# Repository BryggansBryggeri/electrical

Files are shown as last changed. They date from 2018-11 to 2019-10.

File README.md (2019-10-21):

# electrical
Electronics, hardware schematics

## Ethernet Cable Wiring Guide
| Colour 	| Connector 	| Temp [DS18B20] 	| VFD  	| Pressure 	| Float switch 	| Albus 	|
|---	|---	|---	|---	|---	|---	|---	|
| Orange 	| 1 	| + 	| N/A  	| N/A 	| + 	| N/A 	|
| Blå 	| 2 	| - 	| N/A  	| N/A 	| - 	| N/A 	|
| Brun 	| 3 	| Data 	| N/A  	| N/A 	| N/A 	| N/A 	|
| Grön 	| 4 	| N/A 	| Dif+ 	| N/A 	| N/A 	| N/A 	|
| Grön/Vit 	| 5 	| N/A 	| Dif- 	| N/A 	| N/A 	| N/A 	|

## Panel mounted Contact Orientation

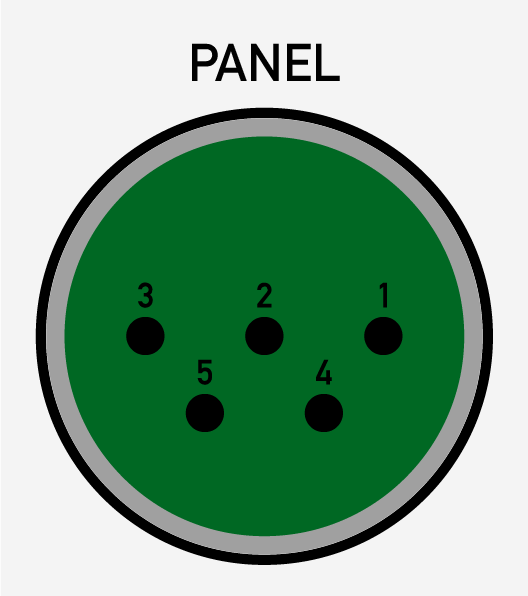
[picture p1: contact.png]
Panel mount diagram


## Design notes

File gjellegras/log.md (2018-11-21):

## 180807

 - Testat ventil med transistorbrygga (ULN2003A). 12V bruten med transistor. Öppnar ventilen med 3.3V styrsignal från Arduino. Ej testat med mjukvarustyrning, men har all anledning och tro att det går.
 - Gjort enkelt kopplingsschema i kicad
 - Tanke: arduino nano, alt. be Erki Pojka om hjälp att göra eget chip.
Idén är att använda färdiga FC-28 fuktsensorer och baserade på analog read släppa på vatten. Idealt också att driva allt med solceller så det är helt självgående. Ingen extern kommunikation i version 1

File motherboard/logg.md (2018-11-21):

# DEVLOGG

## Resources

https://www.makeuseof.com/tag/raspberry-pi-gpio-pins-guide/
https://www.instructables.com/id/Design-a-Raspberry-Pi-Hat-KiCad/

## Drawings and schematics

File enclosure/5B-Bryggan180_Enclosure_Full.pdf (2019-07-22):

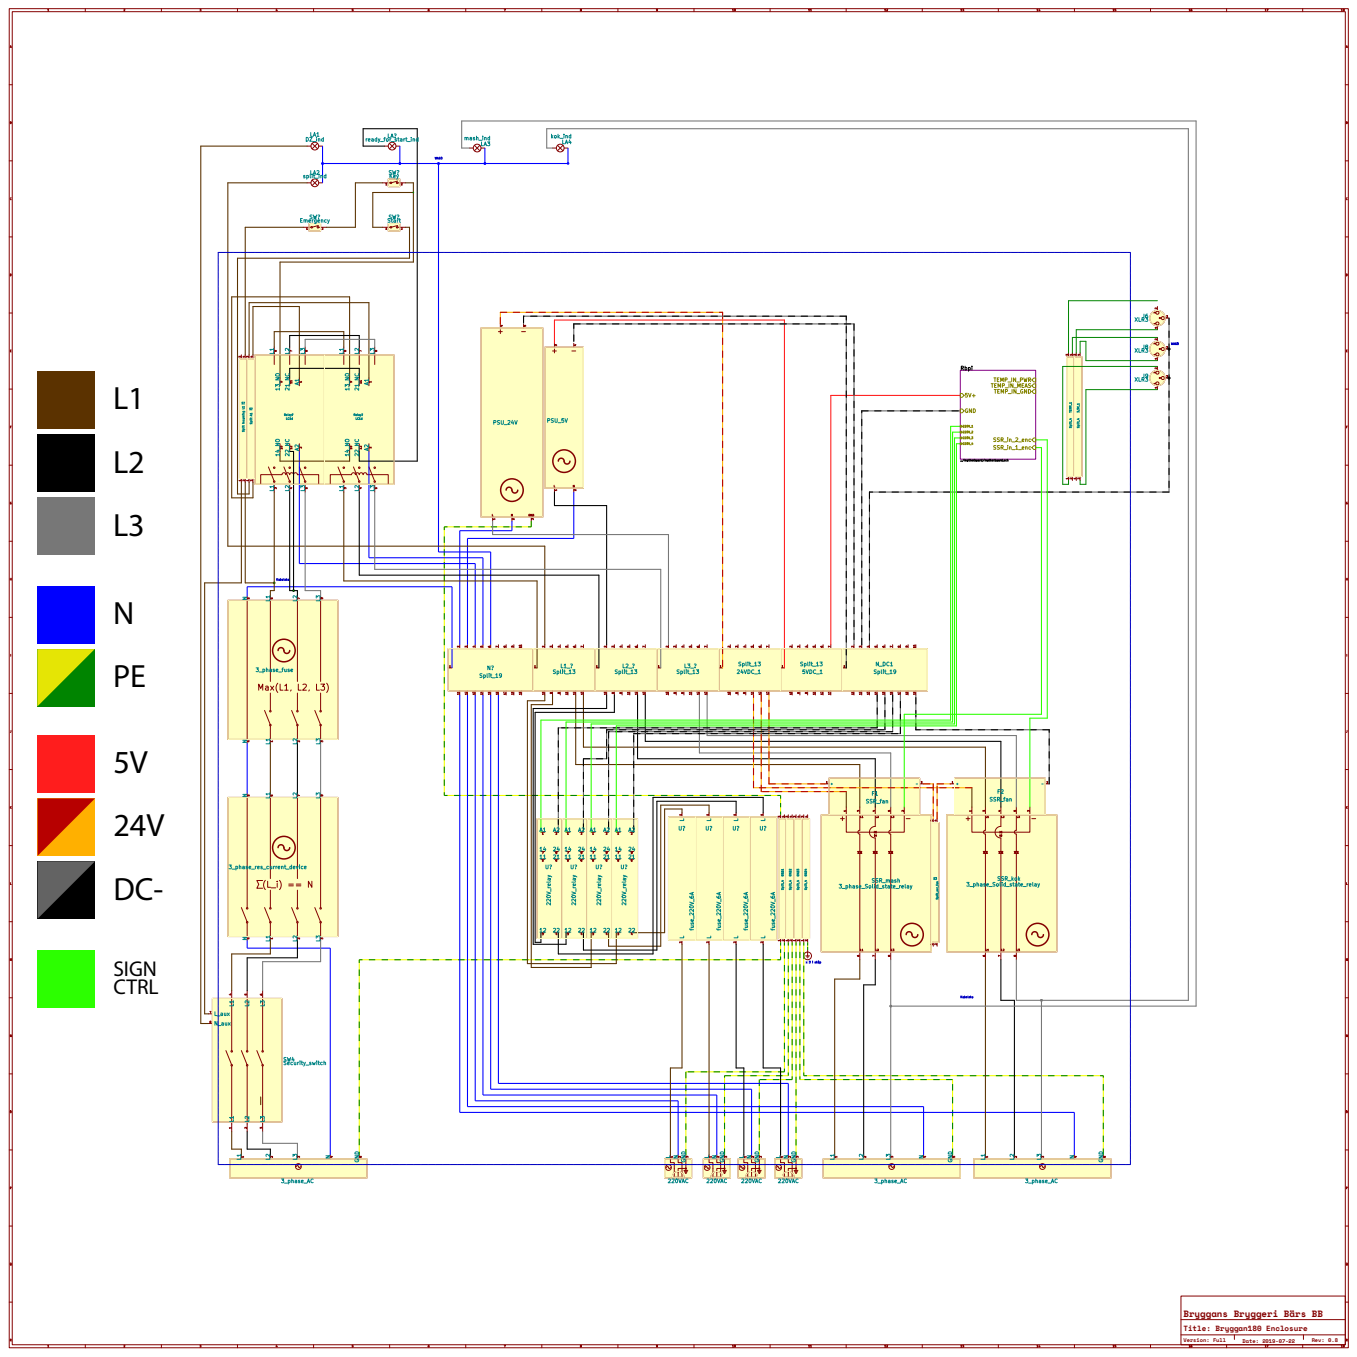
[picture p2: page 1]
Version: Full; Date: 2019-07-22; Rev: 0.8; SIGN CTRL

Bryggans Bryggeri Bärs BB
Title: Bryggan180 Enclosure

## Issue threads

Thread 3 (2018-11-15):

touch screen

jaklindq, 2018-11-15:

JonathanFager, 2019-07-05:
Best would be a used tablet with a rugged case and then a mount on the side of the electrical cabinet (or some other point )

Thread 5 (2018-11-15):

Pump cabinet design

jackonelli, 2018-11-15:
- [x] Decide on dimensions of cabinet
- [x] Decide on cable
- [x] Decide on way to communicate with VFD
- [x] Decide on connectors
- [x] Build

JonathanFager, 2019-05-07:
- [ ] Decide on dimensions of cabinet
- [ ] Decide on cable
- [ ] Decide on way to communicate with VFD
- [ ] Decide on connectors
- [ ] Build

jackonelli, 2019-08-23:
I think we'll branch off a separate issue for the motherboard/rpbi parts of the comm's.
Then we can close this issue if we only decide on cable for comm's between enclosure and pump cabinet.
@swebro any thoughts? RJ45 is expensive so we can use on of those nice ones Jonte found?

Closed 2020-03-20.

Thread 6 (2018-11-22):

opamp comparator for ssr signal indication

jaklindq, 2018-11-22:
Sen så kollar man bara med en opamp i komperator-koppling mellan spänningen vid motståndet och en spänningsreferens (en potentiometer, alla opampar kan använda samma potentiometer som referens), opampen driver i sin tur en led via ett annat motstånd.

Fördelarna med det är att leden bara lyser om det går ström genom SSRen, samt att man isolerar XORen ifrån externa spänningar.

Om man behöver en pull up eller pull down sätter man den parallell med dioden till dit man vill pulla

Closed 2018-12-13.

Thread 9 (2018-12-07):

Double check rbpi pins schema vs footprint

jaklindq, 2018-12-07:

jaklindq, 2018-12-15:
Was correct, although the fact that we mount the rbpi upside down the footprint needed to be rotated to match the mounted pins.

Closed 2018-12-15.

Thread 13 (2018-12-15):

Mosfet swap

jaklindq, 2018-12-15:
Swap places Q1 <--> Q2

Closed 2018-12-16.

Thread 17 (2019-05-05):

Align connectors

jackonelli, 2019-05-05:
Align connectors 2-pin J2-J7 such a 1x8 connector can be used.

They can technically be made into a mutli-unit component since they do not appear in hierarchical sheets used many times.
Not ideal from a schematics point of view but a lot less error prone in the pcb so this is probably best

jackonelli, 2019-08-16:
These connectors does NOT need to be grounded. The transistors just receives the 24VDC signal post load (relay or whatever) and opens to the ground plane on the card. I.e. a single connecting signal path per transistor

jackonelli, 2019-08-16:
Schematically this is actually fine. I moved all connectors to the root of the hierarchical sheets.

jackonelli, 2019-08-16:
Forss approves the removal of ground

Closed 2019-08-19.

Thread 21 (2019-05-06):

Correct power splits

jackonelli, 2019-05-06:
Now that we actually have the ones we are going to use:

 - [x] Make eeschema component
 - [x] Decide placement
 - [x] Switch and rewire

JonathanFager, 2019-05-15:
For the small splits, use 1-to-as many as needed, and we get the jumpers. This will help clean up the schema significantly

Closed 2019-07-01.

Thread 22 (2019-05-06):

VFD in the design

jackonelli, 2019-05-06:
Should we have it in the enclosure? If yes:

- [ ] Eeschema component
- [ ] Decide on placement
- [ ] Wire

JonathanFager, 2019-05-07:
Should not be in the enclosure for now. Closing this issue in favor of #5

Closed 2019-05-07.

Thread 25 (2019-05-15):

220 Outlets Relays

JonathanFager, 2019-05-15:
- [x] eeschema component
- [x] decide on placement
- [x] wire

jackonelli, 2019-07-02:
Be Loka kolla över det nästa gång vi är i lokalen

Closed 2019-08-29.

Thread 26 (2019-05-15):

Fix Start Wiring

JonathanFager, 2019-05-15:
Fix the incorrect implementation of switches for start procedure

Closed 2019-07-01.

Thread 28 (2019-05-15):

Fix Contactor Aux-Relays

JonathanFager, 2019-05-15:
The Contactors have AUX-relays, NO and NC (I think), which could be used for Lights.

Closed 2019-07-01.

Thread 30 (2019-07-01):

Control 220V relays and SSR's with the same driver circuit

jackonelli, 2019-07-01:
I added the hierarchical pins to complete the enclosure kicad but no actual functionality is in the pcb yet

jackonelli, 2019-08-16:
These need the exact same circuit as the SSR driver.
Transition to IC? E.g. http://www.ti.com/lit/ds/symlink/uln2003a.pdf

jackonelli, 2019-08-16:
- Den du länkade är Darlington arrayer, vilket inte är mosfets. Vilket kan vara fine om Raspberryn orkar driva dem

- Ålrajt. Men det finns säkert liknande med många mosfets?

- Det ska det göra
Den där det upp till 1.25mA per ingång, vilket är ganska mycket för Raspberryn
Man får inte dra mer än 16mA per pinne men totalen får inte överstiga 51mA. Det är lätt att glömma det om man börjar koppla på mer och mer saker

- Vi kanske ska gå direkt på en shift register och bara använda 3-pinnar?!?

- Gillar inte shift register. Har man problem med brus kan de vara opålitliga, men i2c io-expanders är nice https://se.farnell.com/microchip/mcp23017t-e-ss/i-o-expansion-16bitar-1-7mhz-ssop/dp/2851558 25mA per pin, 125mA totalt 16 styrbara pinnar i två 8-bitars register. Frågan är om 25mA räcker. Ville inte SSRerna ha typ 45mA, o skulle gissa på att relän vill ha något liknande

swebro, 2019-08-16:
[This](https://se.farnell.com/maxim-integrated-products/max4896etp/rel-drivkrets-8-kan-5-5v-tqfn/dp/2516973) seems like a nice little IC

jackonelli, 2019-08-16:
> [This](https://se.farnell.com/maxim-integrated-products/max4896etp/rel-drivkrets-8-kan-5-5v-tqfn/dp/2516973) seems like a nice little IC
>
> EDIT: It even have Open-Load Detection, so we do not need to implement it ourself.

jackonelli, 2019-08-16:
Closed by mistake.

jackonelli, 2019-08-16:
> [This](https://se.farnell.com/maxim-integrated-products/max4896etp/rel-drivkrets-8-kan-5-5v-tqfn/dp/2516973) seems like a nice little IC
>
> EDIT: It even have Open-Load Detection, so we do not need to implement it ourself.

But can it handle 24V needed for the SSR/relay. It says max Vcc 5.5V but it also says "designed for medium voltage applications up to 50V"

swebro, 2019-08-16:
Yes, it works very similarly to our current design if you look at page 11 of the datasheet.

swebro, 2019-08-16:
If I were to guess, the reason they chose 50V as max is that the internal source-drain capacitance is so large that the energy in the current rush when opening the transistor is enough to arc the junction

swebro, 2019-08-16:
The IC itself is just 5x5mm, so they do not have a lot of room for a wide transistor

jackonelli, 2019-08-16:
We are seriously considering i2c comm for an io expander:
https://www.farnell.com/datasheets/2243622.pdf

jackonelli, 2019-08-19:
Upgrade to opamp with more parallell inputs?

Here is a quad input variant (the tlc272 we currently use is only dual):
https://se.farnell.com/texas-instruments/lm324adr/op-amp-quad-low-power-smd-soic14/dp/8389233

jackonelli, 2019-08-19:
Inspiration:
https://www.abelectronics.co.uk/p/54/io-pi-plus

Closed 2019-08-30.

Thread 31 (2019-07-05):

L1, L2, L3 phases colour error in schematic

jackonelli, 2019-07-05:

jackonelli, 2019-07-05:
När du ändå är igång:
Gör texten nere i höger hörn större också. Skulle bli en mycket finare utskrift

JonathanFager, 2019-07-05:
L1: Brun
L2: Svart
L3: Grå

Closed 2019-08-16.

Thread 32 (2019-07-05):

Floating switch

jackonelli, 2019-07-05:
- [ ] Add to enclosure design
- [ ] Decide on connector
- [ ] Mount connector in enclosure

jackonelli, 2019-07-05:
Indicator is going to be tricky with serial wiring as we have planned.

jackonelli, 2019-08-19:
Simplest option is to have an implicit indicator:

Raspberry GPIO is firing without "AND error" but indicator for SSR is not HIGH. Then it should be the floating switch.

jackonelli, 2019-08-19:
If we want an actual indicator, which would be real nice. Then we could have the floating switch only wired to a Mosfet-style subcircuit which, when floating switch closed, allows SSR signal and indicator to close

JonathanFager, 2019-08-19:
Do we really need an indicator light for this? I agree it should not allow SSR to fire, but a light only for this seems like a feature creep

jackonelli, 2019-08-21:
Feature creep <3. Imagine having a red light go on as we are emptying the mash tun. Undaunted glory.

JonathanFager, 2019-08-30:
We could mount this in a stainless tube that is inserted into the kettles from the top. No need to drill holes.

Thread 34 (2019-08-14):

Serial interface

jackonelli, 2019-08-14:
Will prevent major headaches to have this easily accessible even with active enclosure.

- [ ] Motherboard interface
- [ ] Interior wiring to sensor wall
- [ ] Panel mounted contact (USB)

Cable: https://se.farnell.com/adafruit-industries/954/usb-to-ttl-serial-cable-raspberry/dp/2215041

swebro, 2019-08-14:
I think that having a connector on the PCB so we can have a RJ-RJ cable between it and the connector on the case. [Here](https://github.com/stephane/libmodbus/wiki/Libmodbus-on-Raspberry-pi) is a library to use the internal UART to communicate over modbus, we just need a [tranciever](https://se.farnell.com/analog-devices/adm483earz/transceiver-rs485-250kbps-nsoic/dp/2377088?st=rs485) and a [rs485 line driver](https://www.google.com/search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:) if we want the RPi ti be the master

jackonelli, 2019-08-16:
Sadly, we need the uart pins for the VFD comms.

jackonelli, 2019-08-29:
Terse, and for the rbpi-zero. But this might actually have something:
https://openpunk.com/post/5

Closed 2019-08-16.

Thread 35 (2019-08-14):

Connect all rbpi ground pins to ground plane?

jackonelli, 2019-08-14:

swebro, 2019-08-14:
It depends on a lot of factors. On one hand the stronger ground is connected to itsself the better. But one need to prevent ground loops. [Read this](https://www.autodesk.com/products/eagle/blog/8-pcb-grounding-rules/)

jackonelli, 2019-08-16:
Since the pi itself connects all ground pins to the ground plane, we'll do the same.

Closed 2019-08-16.

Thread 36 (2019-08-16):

Indicator and error signals

jackonelli, 2019-08-16:
These should be feedbacked to rbpi for sure. Do we want lamps on enclosure as well?
The indicators is already in place since we do that directly with one of the SSR output phase (better since we then also show that the SSR is actually working and not only the signal).

The error signal remains. We will still show it (and prohibit it) in software so it is really unlikely that it will ever show.

jackonelli, 2019-08-16:
We'll feedback all the ssr outputs via the i2c io expander #30
error signal will get its own gpio

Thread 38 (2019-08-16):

Calculate total power

jackonelli, 2019-08-16:

JonathanFager, 2019-08-16:
Lamps are 5W each

JonathanFager, 2019-08-16:
Worst case: Fuses trip. Nothing breaks right?

JonathanFager, 2019-08-17:
Fan is 0.062kW

swebro, 2019-10-21:
If we were to draw to much, what could we do about it? Not too much other than limiting the SSR duty cycles. So I think that it is better to measure the currents, for now we could try to borrow a power meter and if we are close we could add one in the system

JonathanFager, 2019-10-22:
Exactly. Our actors could have a property that is powerDraw and Bryggio could make sure that powerDraw never exceeds what we can supply.

For sure Plejd have nice power meeters just laying around.

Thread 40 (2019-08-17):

Add Pressure/Volume sensor

JonathanFager, 2019-08-17:

jackonelli, 2019-08-17:
Not prioritised for first milestones. But nice to drill enclosure parts before mounting in brewery

JonathanFager, 2019-08-19:
There are 2 versions of this. One that delivers an analog signal of 0-5V or one that delivers a signal in the form of mA. Which is to be desired?
@swebro

Also, what is the maximum pressure in kPA that can be expected? Needed to size the sensors correctly. @jackonelli

jackonelli, 2019-08-21:
With 2m fluid height: 121.429 kPa. So that is the absolute maximum.
I'm not sure about the exact height of the vessels

JonathanFager, 2019-08-21:
Boil 52+11.5cm (main+hoptrap)
Assume roughly same on mash

JonathanFager, 2019-08-21:
Boil main volume 158l.
Hoptrap 18l

JonathanFager, 2019-08-21:
70 cm depth gives roughly 7kPa?

jackonelli, 2019-08-21:
I assume we wont be operating the brewery in vacuum?

JonathanFager, 2019-08-21:
It will be very energy efficient to achieve boil of of DMS in a near vacuum.

B stands for Brownian motion

JonathanFager, 2019-08-21:
Now my calculations are not known to be correct. However: I assume that the sensors are calibrated to atmosoherical pressure. So they should be sized go only the added pressure of the water/wort hence 7kPa?

jackonelli, 2019-08-21:
Mais oui

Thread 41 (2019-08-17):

Add Flowsensor

JonathanFager, 2019-08-17:

jackonelli, 2019-08-17:
Not prioritised for first milestones. But nice to drill enclosure parts before mounting in brewery

jackonelli, 2020-03-25:
Verify protocol, see if it works with 0-10V or 4-20mA

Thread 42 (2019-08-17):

Add Enclosure temperature sensor

JonathanFager, 2019-08-17:
A temperature sensor within the enclosure might be a good idea, if only as a temporary thing to monitor cabinet temeperatures and might even in thhe future sound buzzer or trigger E-stop if temperature exceeds say 70oC

jackonelli, 2019-08-17:
Great idea. I think part of it should be implemented. Triggering E-stop seems infeasible though.
How would we control the power to the contactor coil?

jackonelli, 2019-08-17:
We could of course block all output. But not the input?

JonathanFager, 2019-08-19:
I know for a fact that we have a DH11 Sensor lying around. Would be mounted directly on the PCB.
Ping @jackonelli to possibly implement this directly.

JonathanFager, 2019-12-09:
We now got a Ds18b20 in the enclosure.
This works well for all intent and purposes.
Will make a din-clip for ds18b20

JonathanFager, 2019-12-09:
First design iteration, hopefully it'll fit.
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

JonathanFager, 2019-12-09:
[ds18b20clip.zip](https://github.com/BryggansBryggeri/electrical/files/3940114/ds18b20clip.zip)

@jackonelli if you can, please start .gcode file extension on the printer.

JonathanFager, 2019-12-10:
Clip is printed. Probably in the box by the printer at ETA.

Closed 2020-01-25.

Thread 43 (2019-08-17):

Add Buzzer

JonathanFager, 2019-08-17:
Buzzer has two states continuous and pulsing.
Find buzzer and implement this so that both these states can be implemented. i.e Pulse for "Add hops" and Continuous for temperature is to high

jackonelli, 2019-08-17:
Buzzer is in box at ETA

jackonelli, 2019-09-06:
Ø: 26mm. Needs to be mounted on the outside of the enclosure.
Also: needs two separate signal lines: It has three pins, one neutral and two positive.
Positive 1: repeating beep
Positive 2: continuous beep.

Can this be driven low-side? I.e. is it symmetric?

jackonelli, 2019-09-06:
Or we can drive this with continuous signal only, and make beep patterns in software

JonathanFager, 2019-12-10:
Mounting-dinclip is printed. Probably in small box beside printer.
Buzzer is on top of cabinet.

For now, not ideal to have inside of the cabinet, but will have to do for now.

What should the functionality be?

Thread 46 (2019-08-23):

Add temp sensors

jackonelli, 2019-08-23:
- [x] Confirm motherboard v1.0 one-wire interface
- [x] EEschema
- [x] Decide on connectors
- [x] Drill holes for connectors
- [x] Test with connectors

jackonelli, 2019-08-23:
Do we need to "ground" the signal from connector, directly on motherboard for good signal properties?
The alternative is to wire it directly to NDC DIN-split.

==> One less screw terminal on motherboard.

swebro, 2019-08-26:
I would say that it is better to take it to the PCB, otherwise it would be a large zero-resistance loop and would form a quite good transformer

JonathanFager, 2019-10-10:
2 more distances to be made.

Closed 2020-02-09.

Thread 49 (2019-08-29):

Check resistor values

jackonelli, 2019-08-29:
Standardise to this:

https://www.electronics-notes.com/articles/electronic_components/resistors/standard-resistor-values-e-series-e3-e6-e12-e24-e48-e96.php

Also: try to minimise the number of unique R values

swebro, 2020-03-23:
Reminder: Some resistors need to be as close to a specific value as possible

jackonelli, 2020-03-25:
Some calcs left. Will open sub issues. Also did capacitors

Closed 2020-03-25.

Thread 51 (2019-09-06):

PE on SSR

jackonelli, 2019-09-06:
I think they are grounded in the DIN-rail, but there seems to be a dedicated screw for it, see page 6:

http://www.productselection.net/pdf/UK/RGC_2_3A.pdf

swebro, 2019-09-06:
You are correct, it is however normal to have a redundant connection in these kind of components. We could be content with how it is now, but it is better to also connect the ground screw

JonathanFager, 2019-10-10:
Today I crimped two wires for ground. However, they where a PITA to get to.
Measured the resistance from the SSR to different points on the enclosure and it was at max 0.7ohm. => More than good enough
@swebro Please move this back to To Do if you disagree, otherwise close the issue

swebro, 2019-10-17:
It should be good enough

Closed 2019-10-17.

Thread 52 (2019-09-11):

Add extra i2c expander

jackonelli, 2019-09-11:
With two lines required for buzzer(?) #43 we are now filled up

swebro, 2020-03-23:
I've made it easier to add more IO expanders, what do we want them for? Should they all be the same open drain with feedback as the others?

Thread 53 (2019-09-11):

rbpi din mount

jackonelli, 2019-09-11:
- [x] design
- [x] 3d print
- [ ] protective plate / cooling system holder

jackonelli, 2019-09-11:
design at google drive/bryggan180/electrical/raspberry_mount

jackonelli, 2019-09-11:
The print is fine. Need som distances/bottom plate though since the base of the mount interferes with electronic components on pi

JonathanFager, 2019-10-14:
Closing this for now.
If internal temperature is to high during operations, we will open a new issue for this.

Closed 2019-10-14.

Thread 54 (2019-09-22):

Power cord on Boil

JonathanFager, 2019-09-22:
Fix powercord on Boilkettle.
Not much left but some cableshoes.

Closed 2019-11-07.

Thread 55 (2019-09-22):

Power cord on Mash

JonathanFager, 2019-09-22:
- [x] Print Adapter plate. File below
- [x] Test adapterplate+box
- [x] Mount cables

Needs an enclosure to be mounted.

JonathanFager, 2019-10-21:
This should be printed.
Hopefully will work as an adapter plate between "abox" (purchased, at ETA) and the Mashtun
[abox.zip](https://github.com/BryggansBryggeri/electrical/files/3752800/abox.zip)

Closed 2019-11-07.

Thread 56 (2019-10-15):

Mount cable to panelmounted connectors

JonathanFager, 2019-10-15:
- [x] Decide on cable
- [x] Buy Cable
- [x] Decide on wires to use
- [x] Write in documentation what wires to use.
- [x] Solder to panel mounts
- [x] Mount to raspberry

jackonelli, 2019-10-22:
How will the internal cables connect to the motherboard?

When fixing #17 I removed a lot of screw terminals for ground connection on the motherboard. Now the PCB is _only_ connected to DC ground at the power supply terminal.

Closed 2020-02-09.

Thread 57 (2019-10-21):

Float Switches

JonathanFager, 2019-10-21:
- [ ] solder Connectors
- [ ] Connector to box
- [ ] Print second box
- [ ] Test

JonathanFager, 2019-11-03:
I think we should connect there to the entire circuit but not mount them in the kettles at this point. Let's try them out manually (lifting/lowering the switch) outside the kettles for test purposes. After we "brew ourselves in" a few times, we can mount them to the kettles. I think this is a good idea since these are a permanent modification to the vessles.
Suggest to move this to backlog
@jackonelli

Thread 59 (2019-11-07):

#54 Control Powercord on Boilkettle.

JonathanFager, 2019-11-07:
Make sure to control powercord on boilkettle.

- [x] Heat during extended time on
- [x] Current draw
- [x] Resistance per loop

JonathanFager, 2019-11-12:
@jackonelli @swebro What was resistance per loop?

jackonelli, 2019-11-13:
54 ohm from phase to N

JonathanFager, 2020-04-27:
No issue. Just be a bit thoughtful about this in the future

Closed 2020-04-27.

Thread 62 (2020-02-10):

Rbpi sub-enclosure

jackonelli, 2020-02-10:
## General discussion of how to build it.

### Outer

- Materials?
- Dimensions?

### PCB

As large as possible?
Expose all rbpi pins

### Cables

Flat cables for everything?
https://uk.farnell.com/c/cable-wire-cable-assemblies/ribbon-cable-flat-cable

Rbpi to PCB with cable, not mounted.

JonathanFager, 2020-02-10:
So:
An outer case which fits PCB+RPi Side-by-Side.  A flat cable that connects these two.
The outer case will hold several push-style connectors on the outside, and similar on the inside, for ease of disassembling.

Preferably Aluminium or Steel -> Rigid.

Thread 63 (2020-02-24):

Update Wiring Schematic

JonathanFager, 2020-02-24:
An updated Wiring Schematic is really in need.
Should this be done while also marking all cables?

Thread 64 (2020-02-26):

Loose power wire, vcc motherboard

jackonelli, 2020-02-26:

Closed 2020-02-26.

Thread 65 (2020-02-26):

GPIO control broken

jackonelli, 2020-02-26:
Probable causes:

- When someone, currently not present, miss-wired the motherboard, it might have fried the IC's
- Jakob recently made some change to the controlling target in bryggio, might have broken something
- GPIO out from motherboard miss-wired

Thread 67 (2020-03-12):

Power Supply

JonathanFager, 2020-03-12:
- [ ] Reverse Polarity Protection

jackonelli, 2020-03-19:
RPP https://www.farnell.com/datasheets/2200466.pdf

jackonelli, 2020-03-19:
https://uk.farnell.com/infineon/irf5210strlpbf/mosfet-p-100v-d2-pak/dp/1298529

jackonelli, 2020-03-19:
No RPP for now.

swebro, 2020-03-20:
If we will use current loop control (#70) we need to have 24V on the board, so we might want to switch the boost to buck

swebro, 2020-03-20:
We might also want to add some fuses

swebro, 2020-03-20:
Buck: https://uk.farnell.com/texas-instruments/lm2674m-12-nopb/ic-dc-dc-converter-0-5a-smd/dp/3122896

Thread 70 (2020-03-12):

Analog Control VFD

JonathanFager, 2020-03-12:
- [ ] 0-10V/4-20mA?

https://literature.rockwellautomation.com/idc/groups/literature/documents/um/22b-um001_-en-e.pdf

jackonelli, 2020-03-19:
http://ww1.microchip.com/downloads/en/DeviceDoc/22187E.pdf
http://www.ti.com/lit/ds/symlink/lm2902-n.pdf
https://www.farnell.com/datasheets/187592.pdf

swebro, 2020-03-20:
We will have 4st 0-10V (implemted) and 4st 4-20mA (not implemented, reference design will be uploaded shortly) for general purpose control, in the beginning one of them will be used for the VFD until the MODBUS is implemented

swebro, 2020-03-20:
Perhaps we will need 24V for current loop control, so we should change the boost converter to a buck from the 24V

swebro, 2020-03-20:
[Reference design for current loop](https://www.falstad.com/circuit/circuitjs.html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)

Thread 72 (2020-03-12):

Status Led

JonathanFager, 2020-03-12:
- [ ] Update with list of LEDs
- [ ] Decide on placement
- [ ] Any Leds that also should trigger panel mounted lights?

swebro, 2020-03-23:
I've made it easier to add more IO expanders, so we could use a whole one for LEDS, 16 leds controllable from RPi should be plenty and nice to have.

JonathanFager, 2020-03-24:
I dont see a use case for this many LEDs.
When are we going to use LEDs?

swebro, 2020-03-24:
Idk, but blinky led is fun :)

On Tue, Mar 24, 2020, 11:14 AM Jonathan Fager <notifications@github.com>
wrote:

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

swebro, 2020-03-24:
We could use some as led-bars to indicate things

On Tue, Mar 24, 2020, 11:14 AM Jonathan Fager <notifications@github.com>
wrote:

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

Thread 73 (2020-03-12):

General interface & Connectors

JonathanFager, 2020-03-12:
- [ ] Power
- [ ] Ethernet
- [ ] Relay control
- [ ] HDMI ?
- [ ] Albus
- [ ] Shielded cables

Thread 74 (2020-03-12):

Analog Sensors =! Temperature

JonathanFager, 2020-03-12:
- [ ] 0-10V / 4-20mA ?
- [ ] Amplifiers

Are all of these generic? Can the same be used for everything?
Tank height measurment
pH
Pressure
Flow
Turbidity
Colour
etc etc

jackonelli, 2020-03-19:
https://uk.farnell.com/texas-instruments/ads124s08ipbsr/adc-sigma-delta-24bit-4ksps-tqfp/dp/3116586

swebro, 2020-03-23:
We have 4 0-10V and 4 4-20mA, I think that will be plenty. If we need more, it will probably be for external sensors, then we can use an ESP32 for that

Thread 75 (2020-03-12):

RTD PT100 Sensors

JonathanFager, 2020-03-12:
- [ ] Amplifier circut
- [ ]

swebro, 2020-03-23:
4st PT100 is implemented, they are each biased with 5mA and the read voltage uses 3-point compensation to remove lead resistance

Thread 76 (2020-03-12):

UPS/Battery Power

JonathanFager, 2020-03-12:

JonathanFager, 2020-03-12:
https://www.m.nu/strom/pijuice-hat-a-portable-power-platform-for-every-raspberry-pi
Also includes a RTC and some other stuff.
Beaware: To be able to deliver some more oumph a larger external battery is required.
Can be charged through pins, thus charged through our PCB.
Build our own or go with the juice?
Quite expensive.

jackonelli, 2020-03-25:
Issue with power loss:
Pump does not like it.
However: UPS does not solve this since it will not power the pump

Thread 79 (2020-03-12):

W/A/V measurment

JonathanFager, 2020-03-12:
Be able to measure wattage, amperage and voltage.
For each outlet, for each individual powerconsumtion component.
Total
Be able to log and report

jackonelli, 2020-03-25:
Some parts are labelled "Cool-to-have". For most parts, it is where they should remain

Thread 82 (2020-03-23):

On-board temp and humidity sensor

swebro, 2020-03-23:
We want some kind of simple temperature and humidity sensor on the board, preferable i2c interface

jackonelli, 2020-03-25:
dh22 or dht22? Check which one at ETA

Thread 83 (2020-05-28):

Redesign for ADC v_ref

jackonelli, 2020-05-28:
Filter can be made simpler?
See comments in Kicad

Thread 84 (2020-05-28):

Check power spec current conversion resistor, current loop out

jackonelli, 2020-05-28:
P = 0.2W
DAC current loop amp subschema

Too much power in 180R?

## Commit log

2018-11-21 Initial commit of electrical schema
    Starting to design the circuits in the brew enclosure
    Building from the rbpi and outwards.
    Added separate functions as hierarchical sheets,
    not sure if this is best practice.
    [Back_power_protection.sch, SSR_interface.sch, Temp_interface.sch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]
2018-11-21 Ported Gjellegras to new project structure
    [gjellegras.sch]
2018-11-21 Better automatic naming
    [Back_power_protection.sch, SSR_interface.sch, motherboard.sch]
2018-11-22 N-MOSFET driven SSR
    Also opamp comparator for led indication that the SSR's are driven
    Only one SSR is connected since it's a WIP
    [SSR_interface.sch]
2018-12-07 First Motherboard verison ready!
    Changes done at ETA 18-12-06:
    - Moved ssr driver to separate sheet
    - Added gpio protection for temperature sensor
    - Assigned correct footprints
    - Calculated resistor values
    [Back_power_protection.sch, SSR_driver.sch, SSR_interface.sch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]
2018-12-07 +5V: Component --> Power flag
    Had made a custom power component for the voltage. That was a mistake
    Fixed now: as in no footprints needed for all the power flags
    [SSR_driver.sch, SSR_interface.sch, motherboard.sch]
2018-12-10 WIP xor
    [SSR_driver.sch, SSR_interface.sch, Temp_interface.sch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]
2018-12-12 Alternate XOR implementation
    Instead of actual XOR + AND we use NOT + AND
    Now done with only two components:
    one dual AND and one quad 2-input AND (only triple in use)
    [SSR_driver.sch, SSR_interface.sch, Temp_interface.sch]
2018-12-12 Spread all footprints out
    [motherboard.kicad_pcb]
2018-12-13 First routing done!
    [SSR_driver.sch, SSR_interface.sch, Temp_interface.sch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]
2018-12-13 Moved parts around
    [motherboard.kicad_pcb]
2019-01-02 Ready for print?
    [SSR_interface.sch, Temp_interface.sch, motherboard.kicad_pcb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]
2019-01-08 Added second SSR connector
    [SSR_driver.sch, SSR_interface.sch, Temp_interface.sch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]
2019-01-08 Moving to RPI hat PCB
    [SSR_interface.sch, motherboard.kicad_pcb, motherboard_org.kicad_pcb]
2019-03-20 Cosmetic changes
    [motherboard.kicad_pcb]
2019-03-20 Fixed dual and
    [SSR_driver.sch, SSR_interface.sch, Temp_interface.sch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]
2019-03-20 Rev1.0 as sent to print
    [SSR_driver.sch, SSR_interface.sch, Temp_interface.sch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]
2019-03-21 Started enclosure schematic
    [enclosure.kicad_pcb, enclosure.sch]
2019-03-21 File structure
    [enclosure.kicad_pcb, enclosure.sch]
2019-03-21 Added motherboard
    Motherboard (rbpi) as a hierarchical sheet
    Needed to do some changes in order to expose hier. pins to enclosure.
    [SSR_driver.sch, SSR_interface.sch, Temp_interface.sch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]
2019-03-21 Enclosure schematic start
    [SSR_driver.sch, comparator.sch, enclosure.sch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]
2019-03-22 Enclosure Rev 0.5
    Key + Emergency stop breaks N not L1 (i.e. after contactor)
    [enclosure.sch]
2019-03-22 Splits, SSR driver bug
    [SSR_driver.sch, SSR_interface.sch, Temp_interface.sch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]
2019-03-22 Added: SSR fan, Proper splits
    [enclosure.sch]
2019-03-23 Proper N for DZ lamp. Nicer symbols
    [SSR_driver.sch, SSR_interface.sch, Temp_interface.sch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]
2019-03-26 Full wiring
    [SSR_driver.sch, SSR_interface.sch, Temp_interface.sch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]
2019-05-03 Phase -> GND bug
    [enclosure.sch]
2019-05-03 Larger fontsize
    [enclosure.sch]
2019-05-06 WIP: Changing offices
    [enclosure.sch]
2019-05-14 Correct power splits, rewire
    [enclosure.sch]
2019-05-15 10A fuses + ssr signal bug fix
    [enclosure.sch]
2019-05-15 More advanced 3P relay
    [enclosure.sch]
2019-05-15 Tmp prototype relay
    [SSR_driver.sch, SSR_interface.sch, Temp_interface.sch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]
2019-05-16 New file: Drawing from Power in -> Splitter
    [enclosure_threephase_in.sch]
2019-05-16 My take on the new double relay design
    - Relay symbol from lib
    - Emergency and key in series
    [enclosure_threephase_in.sch]
2019-05-16 Added proper split for relay14
    [enclosure_threephase_in.sch]
2019-06-28 For Jontes eyes only
    [enclosure_threephase_in.sch]
2019-07-01 Relay security as sent to Loka
    [enclosure_threephase_in.sch]
2019-07-01 Restructure no cable
    [SSR_driver.sch, SSR_interface.sch, Temp_interface.sch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]
2019-07-01 Library changes for simpler wiring
    [enclosure.sch]
2019-07-01 Low hanging wires
    [enclosure.sch]
2019-07-01 Everything but double contactor and sensor
    [enclosure.sch]
2019-07-01 v0.6 Feature complete!!!
    [enclosure.sch, motherboard.sch]
2019-07-22 Added pdf for full enclosure drawing revision 0.8
2019-10-21 Creat Readme + Etherner Cable Wiring Guide
    Documentation of Ethernet wiring
